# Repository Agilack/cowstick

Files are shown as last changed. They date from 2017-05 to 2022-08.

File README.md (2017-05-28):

# Cowstick

The goal of Cowstick project is to create usefull tools for microcontroller
and FPGA development, for example JTAG/SWD probes, serial port adapter ...
This tools are not revolutionnary in their functions but offer a more
user-friendly approach based on network communication.

## usbkey-ios

This is the first member of cowstick familly. At this time, this key is only
a proof of concept. It contains a microcontroller with USB interface, and
many configurable IOs.

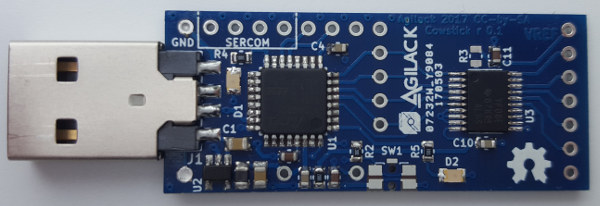
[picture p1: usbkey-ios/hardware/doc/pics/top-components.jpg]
Picture of cowstick usbkey


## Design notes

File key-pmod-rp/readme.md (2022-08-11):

PMOD usbkey
===========

This usb-key is part of cowstick boards family and offer a compact PMOD host
interface. It can be used to test or use most 3,3V PMOD devices, for other
power supplies, a level translator should be used.

For the moment, this module is not supported by cowlab but will be added
soon.

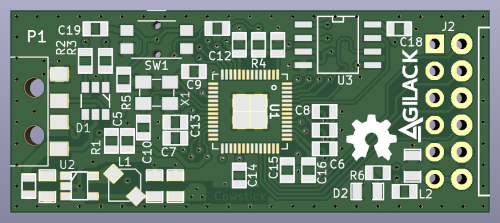
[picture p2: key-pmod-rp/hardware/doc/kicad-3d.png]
Preview of the board


CAD source
----------

This board has been designed using KiCad EDA (version 6). All sources files
(schematics, routing, ...) are available into the `hardware/prj-kicad` folder.

<table>
<tr>
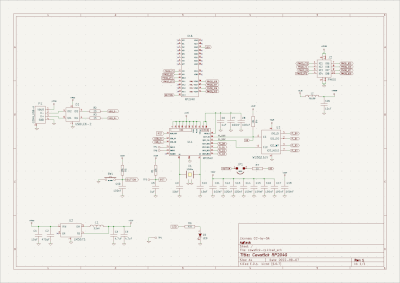
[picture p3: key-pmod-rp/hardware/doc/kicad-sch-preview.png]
KiCad schematics
<td></td>
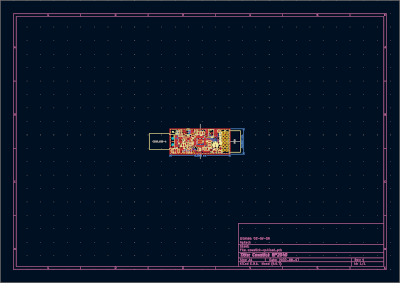
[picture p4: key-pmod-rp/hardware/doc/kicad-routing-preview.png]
KiCad routing
<td></td>
</tr>
<tr>
<td>Fig1: Preview of the KiCad schematics</td>
<td>Fig2: Preview of the KiCad routing</td>
</tr>
</table>

License
-------

This project is OpenHardware. You can use (and/or modify) this project under
terms of the Creative Commons ShareAlike license (CC-by-SA).
See [hardware/LICENSE.md](hardware/LICENSE.md).

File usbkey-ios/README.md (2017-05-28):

# Cowstick usbkey

This USB-key is part of the cowstick boards family. It is a very compact and
low-cost module that allow to connect and communicate with many serial ports
(like ICSP, JTAG, SPI, SWD, ...) over USB. This module can also be used with
cowlab tools to offer a user-friendly interface :)

Picture of cowstick usbkey

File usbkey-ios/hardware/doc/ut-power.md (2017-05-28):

Power unit-test
===============

The goal of this test is to validate the 3.3V regulator.

No load
-------

The first step is tu start the regulator without load. At this point a bug
has been detected : the EN pin mus NOT be left floating (see 7.4.3 of LM3671
datasheet). To fix this, a strap has been added between VIN and EN pin.

 * Input : 5V from laboratory power supply
 * Mesured output voltage (at TP3) : 3.38V
 * Mesured ripple : 29.2mV, main freq 30.30kHz

The device is in PFM mode, this values are acceptable.

Light load
----------

In this second test, a small resistive load (100ohm) has been connected to TP3.

 * Input : 5V (mesured input current : 30mA)
 * Mesured output voltage (at TP3) : 3.34V
 * Mesured ripple : 39.2mV

Large load
----------

This test has not been made yet.

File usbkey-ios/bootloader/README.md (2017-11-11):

# Cowstick Bootloader

To offer a simple and flexible firmware upgrade, cowstick contains a bootloader.
This program also provide an API to allow main application to reuse functions
and avoid multiple copies of generic methods. Here a list of main features :

  * Network oriented interface (show as Ethernet over USB interface),
  * Contains a minimalist HTTP server (not already available)
  * Small memory footprint (less than 20kB)
  * API to allow reuse functions into main firmware

# Usage

The bootloader is placed at the begining of flash memory, where processor
start code execution. In all cases, peripherals and low-level initialization
are made on startup (configure IOs, clocks, ...). At this point, three is
three possible behaviors :

 * If the push button is pressed on startup, cowstick start in bootloader
   mode.
 * Flash is read at address 0x4000. If a valid stack address is found
   (an address that point into internal SRAM) then, the bootloader get firmware
   entry address from second vector (at 0x4004) and jump at this address.
 * If no valid stack address is found, firmware is considered invalid and
   cowstick start in bootloader mode.

## License

CowStick-bootloader is free software: you can redistribute it and/or modify it
under the terms of the GNU Lesser General Public License version 3 as published
by the Free Software Foundation. You should have received a copy of the GNU
Lesser General Public License along with this program, see LICENSE.md file for
more details. This program is distributed WITHOUT ANY WARRANTY.

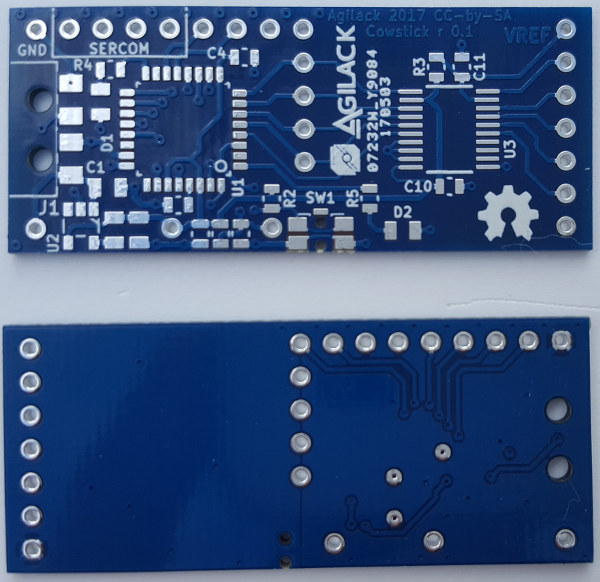
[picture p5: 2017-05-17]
usbkey-ios/hardware/doc/pics/pcb-only.jpg

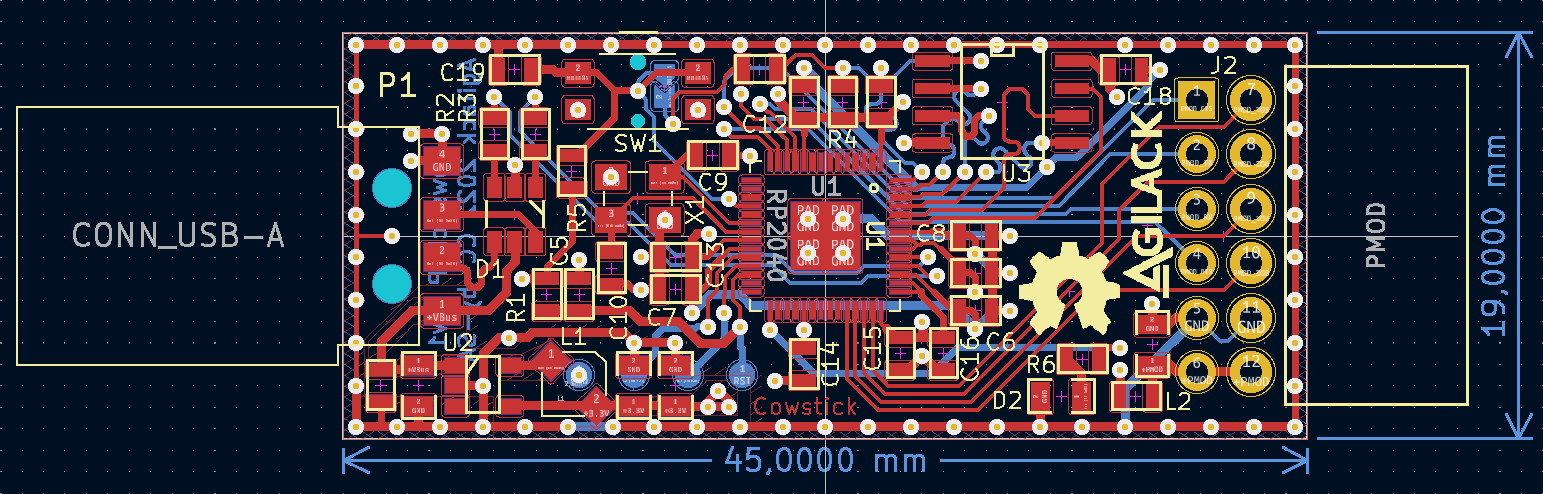
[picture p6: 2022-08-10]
key-pmod-rp/hardware/doc/pcb-preview.png

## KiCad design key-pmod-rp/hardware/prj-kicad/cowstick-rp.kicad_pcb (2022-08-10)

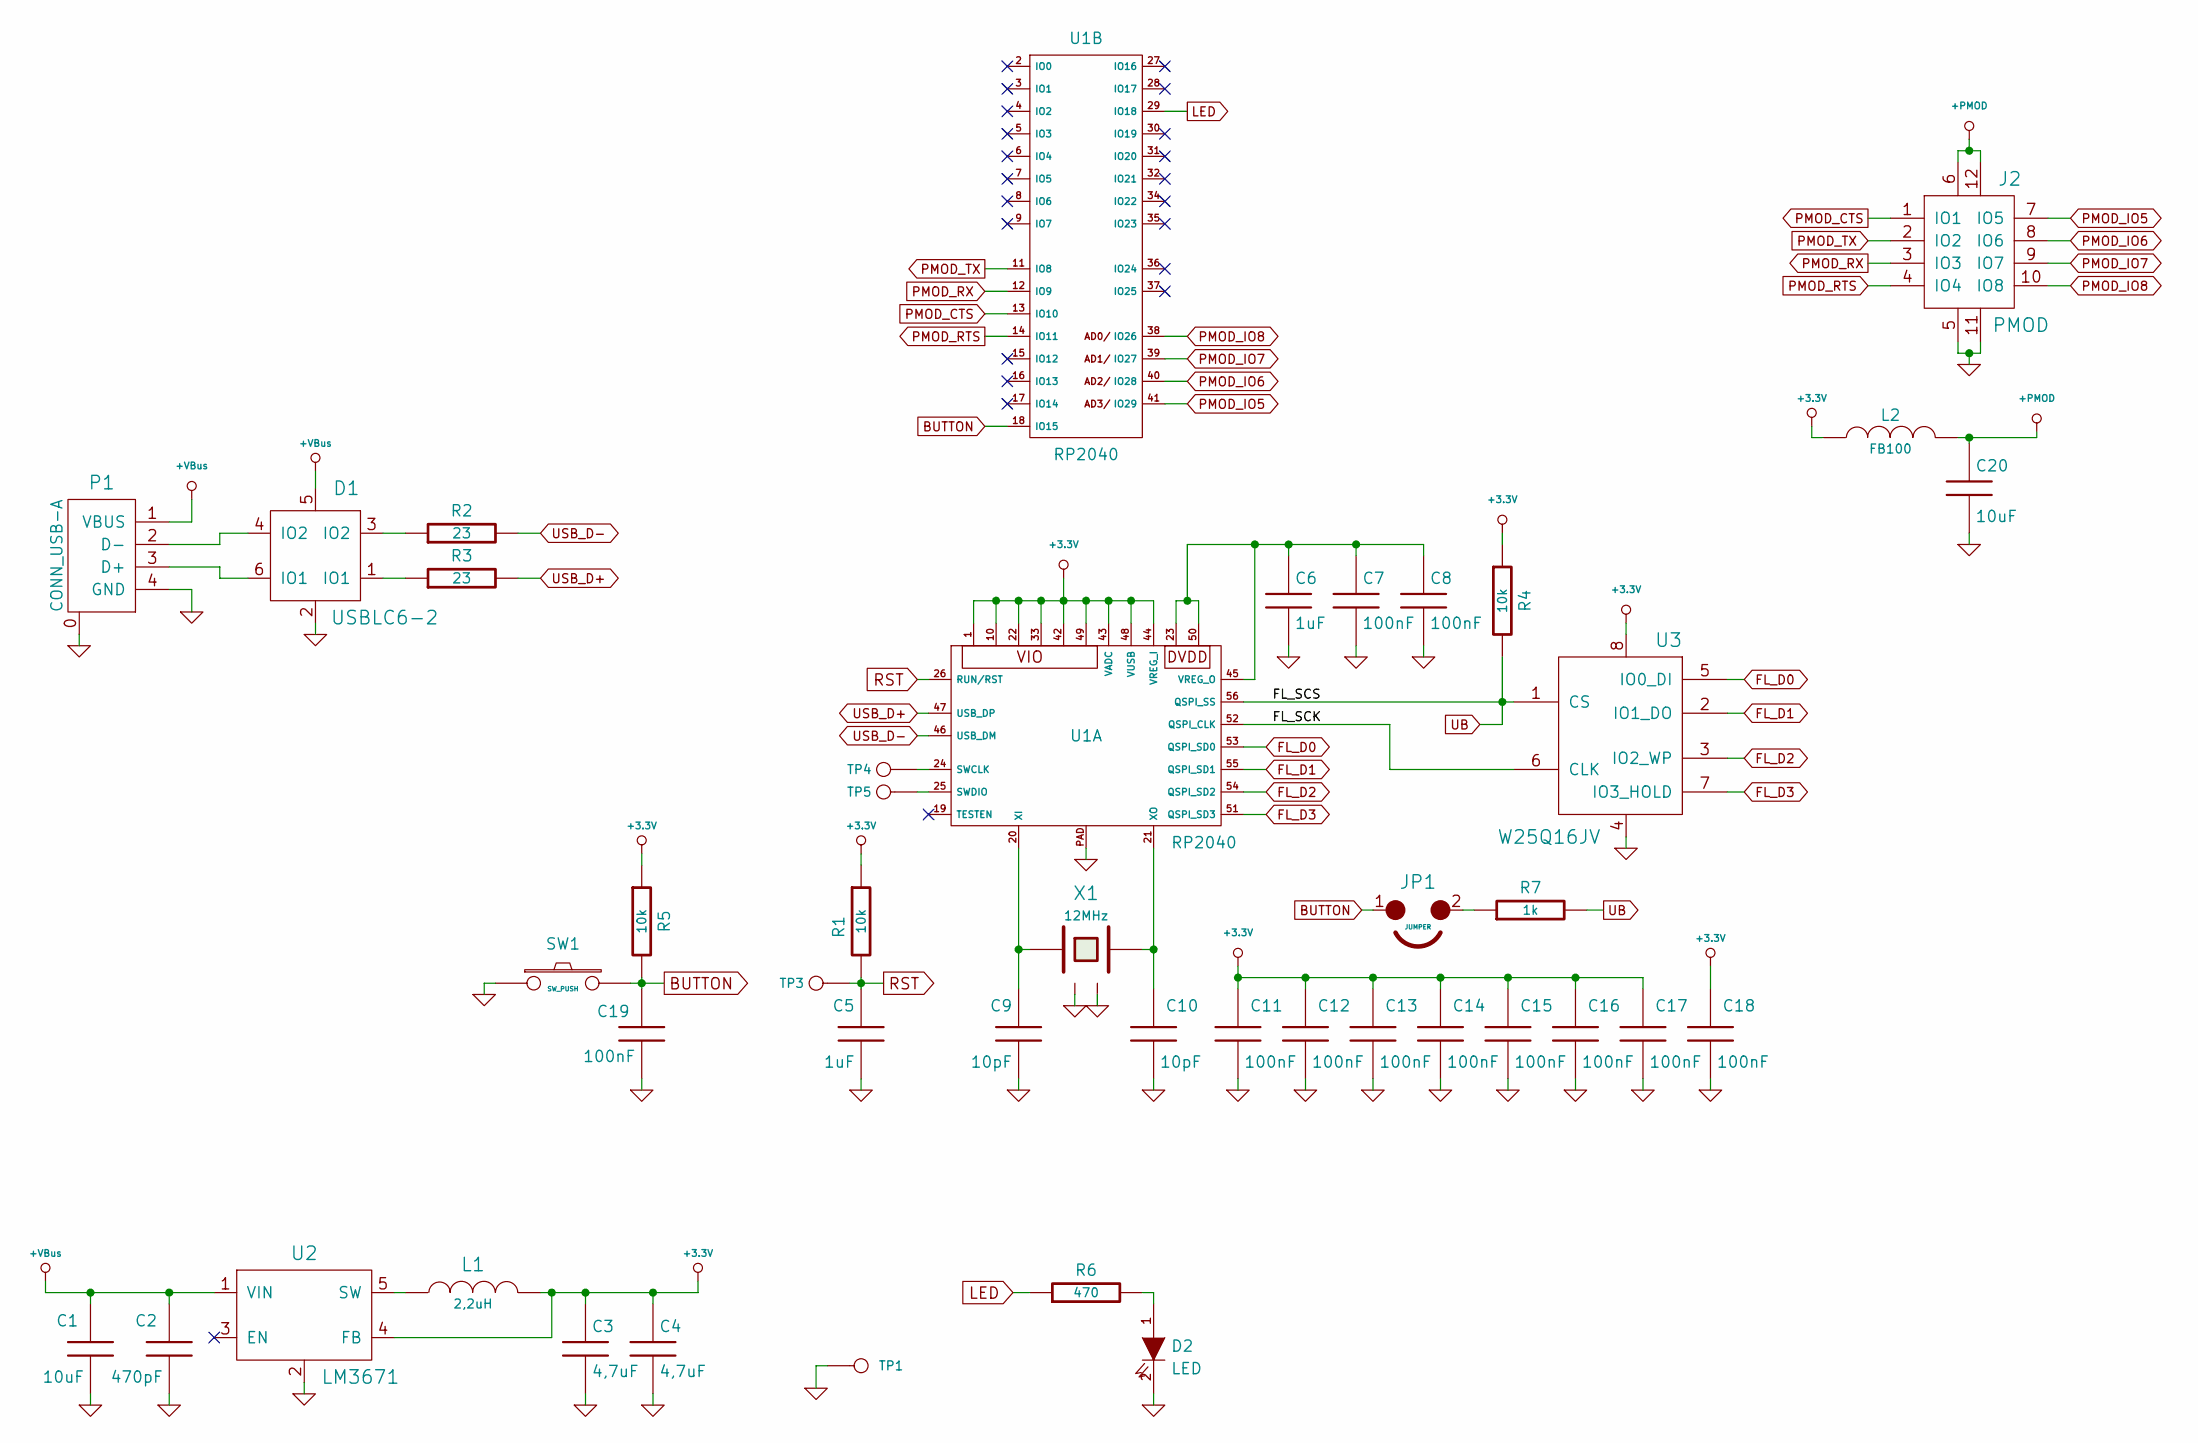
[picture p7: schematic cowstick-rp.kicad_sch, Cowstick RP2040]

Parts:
C1, C20: 10uF; SMD0805
C2: 470pF; SMD0603
C3, C4: 4,7uF; SMD0805
C5, C6: 1uF; SMD0603
C7, C8, C11, C12, C13, C14, C15, C16, C17, C18, C19: 100nF; SMD0603
C9, C10: 10pF; SMD0603
D1: USBLC6-2; SOT23-6
D2: LED; SMD0805
J2: PMOD; PMOD_SSW106-RA
JP1: JUMPER; TP_JP
L1: 2,2uH; I_CDRH2D14
L2: FB100; SMD0603
P1: CONN_USB-A; CONN_MC32604
R1, R4, R5: 10k; SMD0603
R2, R3: 23; SMD0603
R6: 470; SMD0603
R7: 1k; SMD0603
SW1: SW_PUSH; SW_436351045816
TP1, TP3, TP4, TP5: CONN_1; TP_SMD
U1: RP2040; QFN56
U2: LM3671; SOT23-5
U3: W25Q16JV; SOIC-8
X1: 12MHz; Q_3.2x2.5

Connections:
+3.3V: C3.1, C4.1, C11.1, C12.1, C13.1, C14.1, C15.1, C16.1, C17.1, C18.1, L1.2, L2.1, R1.1, R4.1, R5.1, U1.1, U1.10, U1.22, U1.33, U1.42, U1.43 (VADC), U1.44 (VREG_I), U1.48 (VUSB), U1.49, U2.4 (FB), U3.8
+PMOD: C20.1, J2.6, J2.12, L2.2
+VBus: C1.1, C2.1, D1.5, P1.1 (VBUS), U2.1 (VIN)
/FL_SCK: U1.52 (QSPI_CLK), U3.6 (CLK)
BUTTON: C19.1, JP1.1, R5.2, SW1.2, U1.18 (IO15)
FL_D0: U1.53 (QSPI_SD0), U3.5 (IO0_DI)
FL_D1: U1.55 (QSPI_SD1), U3.2 (IO1_DO)
FL_D2: U1.54 (QSPI_SD2), U3.3 (IO2_WP)
FL_D3: U1.51 (QSPI_SD3), U3.7 (IO3_HOLD)
GND: C1.2, C2.2, C3.2, C4.2, C5.2, C6.2, C7.2, C8.2, C9.2, C10.2, C11.2, C12.2, C13.2, C14.2, C15.2, C16.2, C17.2, C18.2, C19.2, C20.2, D1.2, D2.2 (K), J2.5, J2.11, P1.0, P1.4 (GND), SW1.1, TP1.1, U1.PAD, U2.2, U3.4, X1.2, X1.4
LED: R6.1, U1.29 (IO18)
unnamed: C6.1, C7.1, C8.1, U1.23, U1.45 (VREG_O), U1.50
unnamed: C9.1, U1.20 (XI), X1.1
unnamed: C10.1, U1.21 (XO), X1.3
unnamed: D1.1 (IO1), R3.1
unnamed: D1.3 (IO2), R2.1
unnamed: D1.4 (IO2), P1.2 (D-)
unnamed: D1.6 (IO1), P1.3 (D+)
unnamed: D2.1 (A), R6.2
unnamed: L1.1, U2.5 (SW)
unnamed: JP1.2, R7.1
unnamed: TP4.1, U1.24 (SWCLK)
unnamed: TP5.1, U1.25 (SWDIO)
PMOD_CTS: J2.1 (IO1), U1.13 (IO10)
PMOD_IO5: J2.7 (IO5), U1.41 (IO29)
PMOD_IO6: J2.8 (IO6), U1.40 (IO28)
PMOD_IO7: J2.9 (IO7), U1.39 (IO27)
PMOD_IO8: J2.10 (IO8), U1.38 (IO26)
PMOD_RTS: J2.4 (IO4), U1.14 (IO11)
PMOD_RX: J2.3 (IO3), U1.12 (IO9)
PMOD_TX: J2.2 (IO2), U1.11 (IO8)
RST: C5.1, R1.2, TP3.1, U1.26 (RUN/RST)
UB: R4.2, R7.2, U1.56 (QSPI_SS), U3.1 (CS)
USB_D+: R3.2, U1.47 (USB_DP)
USB_D-: R2.2, U1.46 (USB_DM)

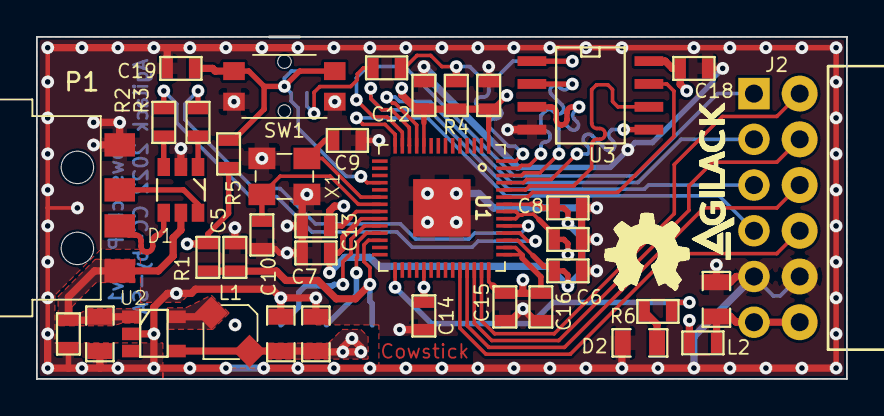
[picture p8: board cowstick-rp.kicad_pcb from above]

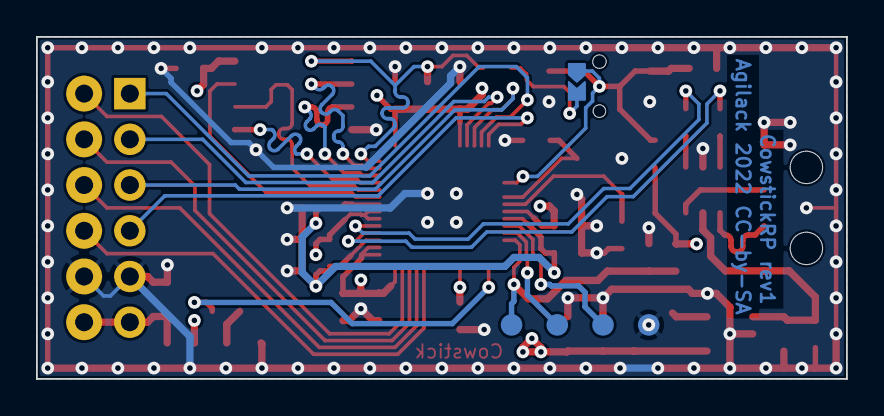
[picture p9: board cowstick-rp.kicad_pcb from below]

Board: 4 copper layers, 45.0 x 19.0 mm, 45 parts (5 on the bottom side), 35 nets.

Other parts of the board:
agilack-11.5: 450px; logo-agilack
ohw_logo: VAL**; logo-ohw

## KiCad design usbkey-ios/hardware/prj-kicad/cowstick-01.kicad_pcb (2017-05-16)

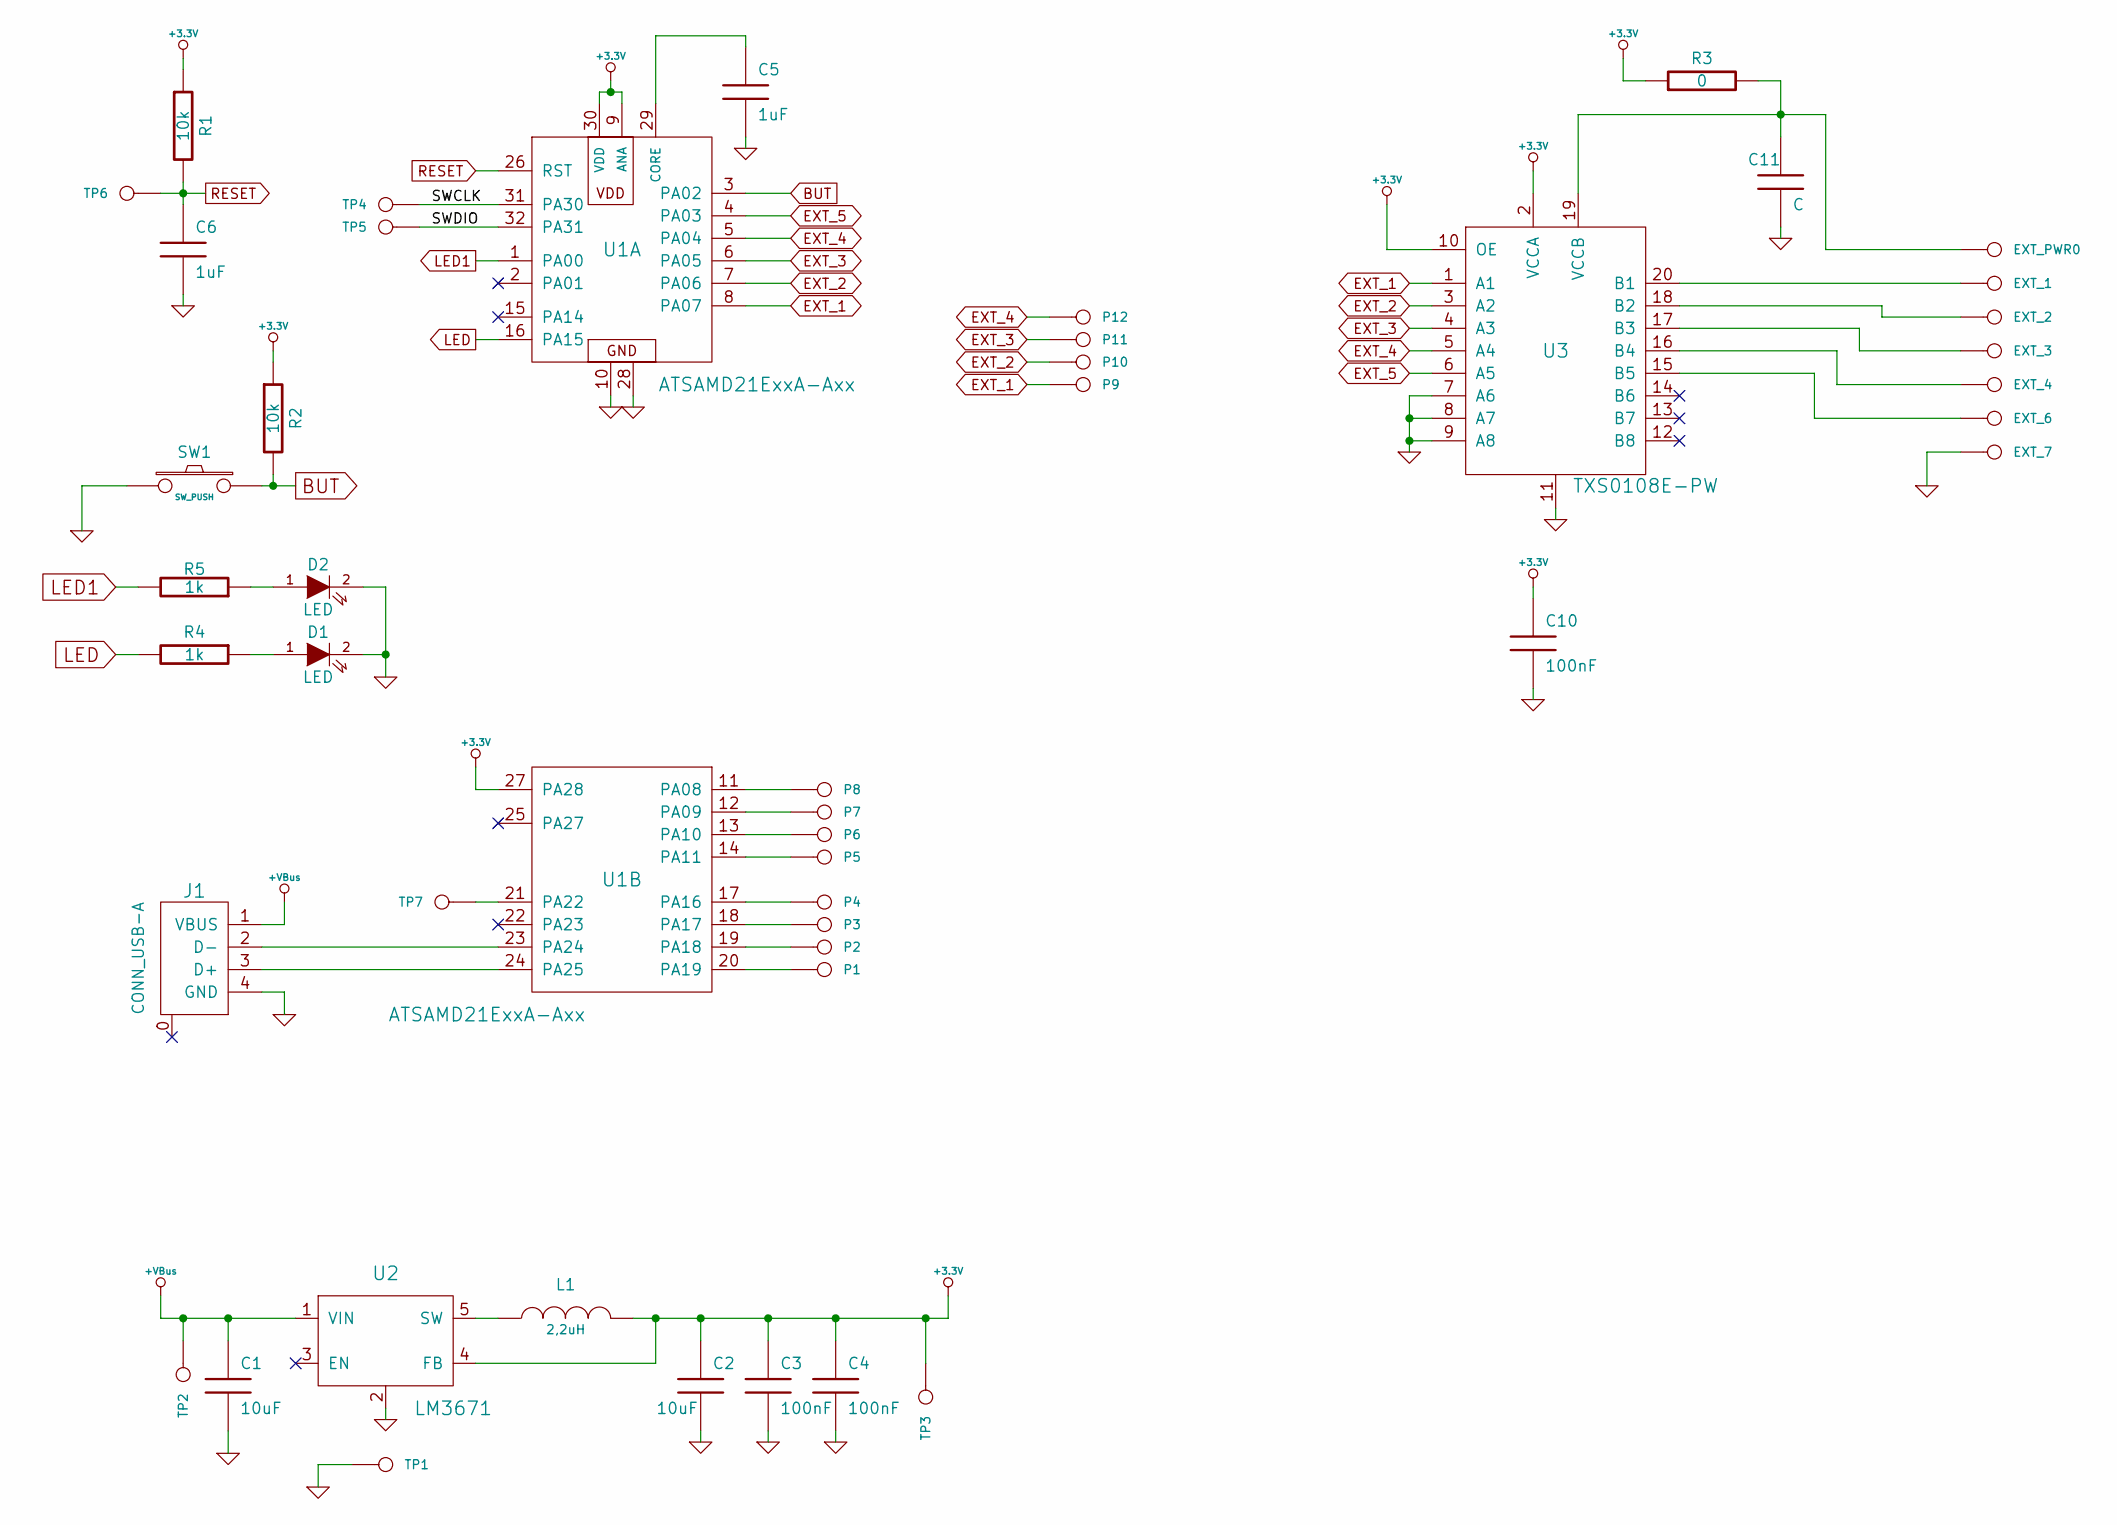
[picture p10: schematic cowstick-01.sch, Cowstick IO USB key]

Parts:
C1, C2: 10uF; SMD0805
C3, C4, C10: 100nF; SMD0603
C5, C6: 1uF; SMD0603
C11: C; SMD0603
D1, D2: LED; SMD0805
EXT_1, EXT_2, EXT_3, EXT_4, EXT_6, EXT_7: CONN_1; TP
EXT_PWR0: CONN_1; TP
J1: CONN_USB-A; CONN_MC32604
L1: 2,2uH; SMD0805
P1, P2, P3, P4, P5, P6, P7, P8, P9, P10, P11, P12: CONN_1; TP
R1, R2: 10k; SMD0603
R3: 0; SMD0603
R4, R5: 1k; SMD0603
SW1: SW_PUSH; SW_PTS840
TP1, TP2, TP3, TP6: CONN_1; TP
TP4, TP5, TP7: CONN_1; TP_SMD
U1: ATSAMD21ExxA-Axx; TQFP32
U2: LM3671; SOT23-5
U3: TXS0108E-PW; TSSOP20

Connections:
+3.3V: C2.1, C3.1, C4.1, C10.1, L1.2, R1.1, R2.1, R3.1, TP3.1, U1.9 (ANA), U1.27 (PA28), U1.30 (VDD), U2.4 (FB), U3.2 (VCCA), U3.10 (OE)
+VBus: C1.1, J1.1 (VBUS), TP2.1, U2.1 (VIN)
/SWCLK: TP4.1, U1.31 (PA30)
/SWDIO: TP5.1, U1.32 (PA31)
BUT: R2.2, SW1.1, U1.3 (PA02)
EXT_1: P9.1, U1.8 (PA07), U3.1 (A1)
EXT_2: P10.1, U1.7 (PA06), U3.3 (A2)
EXT_3: P11.1, U1.6 (PA05), U3.4 (A3)
EXT_4: P12.1, U1.5 (PA04), U3.5 (A4)
EXT_5: U1.4 (PA03), U3.6 (A5)
GND: C1.2, C2.2, C3.2, C4.2, C5.2, C6.2, C10.2, C11.2, D1.2 (K), D2.2 (K), EXT_7.1, J1.4 (GND), SW1.2, TP1.1, U1.10, U1.28, U2.2, U3.7 (A6), U3.8 (A7), U3.9 (A8), U3.11
LED: R4.2, U1.16 (PA15)
LED1: R5.2, U1.1 (PA00)
unnamed: C5.1, U1.29 (CORE)
unnamed: C11.1, EXT_PWR0.1, R3.2, U3.19 (VCCB)
unnamed: D1.1 (A), R4.1
unnamed: D2.1 (A), R5.1
unnamed: EXT_1.1, U3.20 (B1)
unnamed: EXT_2.1, U3.18 (B2)
unnamed: EXT_3.1, U3.17 (B3)
unnamed: EXT_4.1, U3.16 (B4)
unnamed: EXT_6.1, U3.15 (B5)
unnamed: J1.2 (D-), U1.23 (PA24)
unnamed: J1.3 (D+), U1.24 (PA25)
unnamed: L1.1, U2.5 (SW)
unnamed: P1.1, U1.20 (PA19)
unnamed: P2.1, U1.19 (PA18)
unnamed: P3.1, U1.18 (PA17)
unnamed: P4.1, U1.17 (PA16)
unnamed: P5.1, U1.14 (PA11)
unnamed: P6.1, U1.13 (PA10)
unnamed: P7.1, U1.12 (PA09)
unnamed: P8.1, U1.11 (PA08)
unnamed: TP7.1, U1.21 (PA22)
RESET: C6.1, R1.2, TP6.1, U1.26 (RST)

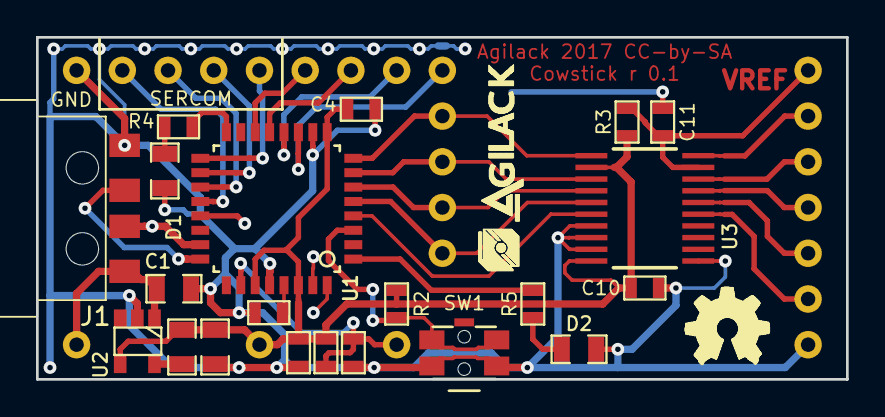
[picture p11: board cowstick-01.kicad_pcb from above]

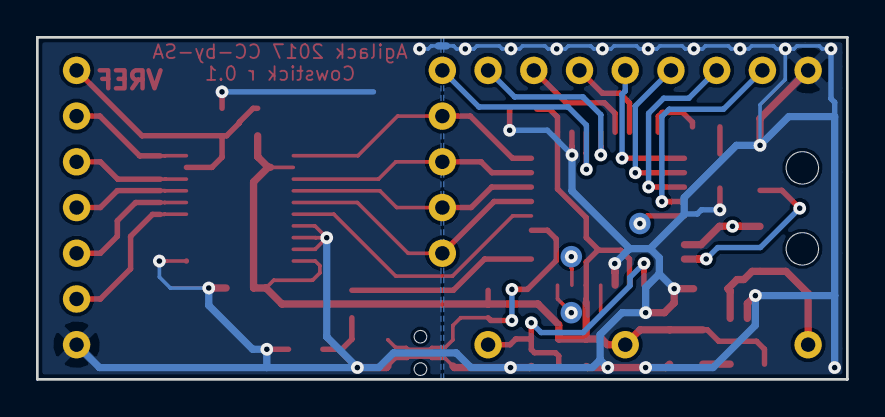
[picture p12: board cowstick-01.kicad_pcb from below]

Board: 2 copper layers, 45.0 x 19.0 mm, 49 parts (3 on the bottom side), 35 nets.

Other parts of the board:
agilack-11.5: 450px; agilack-11.5
ohw_logo: VAL**; ohw-logo

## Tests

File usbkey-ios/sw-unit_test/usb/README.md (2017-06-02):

# USB unit-test

The goal of this program is to develop a USB stack for cowstick. This is put
into a unit-test to offer a simple way to test it :)

## Why ??

If your read this the first question that comes to mind is probably "Why a
custom USB stack ?" There are two main reasons :

 * The "official" atmel/microchip stack use static datas (like usb_d_inst or
   dev_inst) For cowstick, i want to share code of USB stack between bootloader
   and firmware and that's a bit more difficult with static datas.

 * All the stacks i've seen are written to be portable and/or generic. This
   is great but use lot of code. This one is made to have a small memory
   footprint. I want (i hope) a bootloader that fits into less than 16kB.

## HID Mouse

The unit-test contains an HID mouse. This is one of the simplest device (only
one endpoint) that is easy to test (detected by all OS). When loaded this
virtual mouse will move automatically into a square.

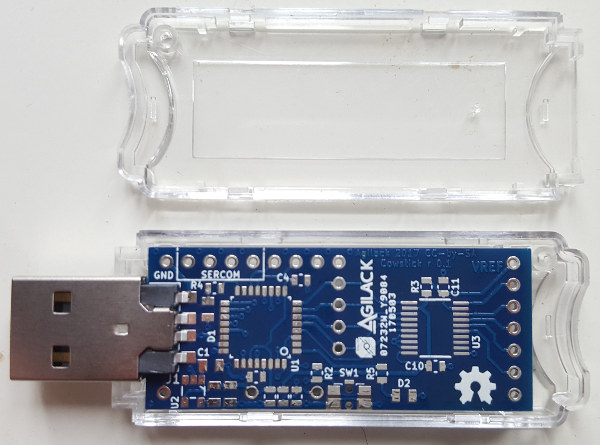
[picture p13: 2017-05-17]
usbkey-ios/hardware/doc/pics/enclosure-test.jpg

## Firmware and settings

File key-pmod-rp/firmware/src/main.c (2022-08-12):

/**
 * @file  main.c
 * @brief Entry point and main function of the firmware
 *
 * @author Saint-Genest Gwenael <gwen@cowlab.fr>
 * @copyright Cowlab (c) 2022
 *
 * @page License
 * This firmware is free software: you can redistribute it and/or modify it
 * under the terms of the GNU General Public License version 3 as published
 * by the Free Software Foundation. You should have received a copy of the
 * GNU General Public License along with this program, see LICENSE.md file
 * for more details.
 * This program is distributed WITHOUT ANY WARRANTY.
 */
#include "pico/stdlib.h"
#include <stdlib.h>
#include <stdio.h>
#include <string.h>
#include <ctype.h>
#include "serial.h"

#undef USE_ECHO

void u_process(void);

/**
 * @brief Entry point of C code
 *
 * This function is called by low-level reset handler. This can be after a
 * power-on, an hardware or software reboot, and after some critical errors.
 * This function should never returns.
 */
int main()
{
	stdio_init_all();

	/* Wait a bit after start to allow VCP to resync */
	sleep_ms(2000);
	printf("--=={ Cowstick-RP }==--\n");

	serial_init();

	while(1)
	{
		if (serial_rx_avail() > 0)
			u_process();
	}
}

void u_process(void)
{
	char data[64];
	char msg[80];
	int len;

	memset(data, 0, 64);
	/* Get data received from uart */
	serial_read(data, 63);
	/* Write debug message to standard output */
	sprintf(msg, "[%s]\r\n", data);
	printf("%s", data);
#ifdef USE_ECHO
	/* Send debug message to uart itself as echo */
	serial_write(msg, strlen(msg));
#endif
}
/* EOF */

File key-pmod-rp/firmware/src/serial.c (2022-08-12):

/**
 * @file  serial.c
 * @brief Handle communication with UART interface
 *
 * @author Saint-Genest Gwenael <gwen@cowlab.fr>
 * @copyright Cowlab (c) 2022
 *
 * @page License
 * This firmware is free software: you can redistribute it and/or modify it
 * under the terms of the GNU General Public License version 3 as published
 * by the Free Software Foundation. You should have received a copy of the
 * GNU General Public License along with this program, see LICENSE.md file
 * for more details.
 * This program is distributed WITHOUT ANY WARRANTY.
 */
#include "pico/stdlib.h"
#include "hardware/irq.h"
#include "hardware/uart.h"
#include "serial.h"

static void serial_irq(void);

static uint8_t rx_buffer[SERIAL_RX_SZ];
static volatile int rx_index_r, rx_index_w;

/**
 * @brief Initialize the "serial" module
 *
 * This function initialize the serial module and configure UART interface. For
 * this driver to work properly, this function must be called before any other
 * serial functions.
 */
void serial_init(void)
{
	/* Initialize indexes of buffers */
	rx_index_r = 0;
	rx_index_w = 0;

	uart_init(uart1, 115200);

	gpio_set_function(8, GPIO_FUNC_UART);
	gpio_set_function(9, GPIO_FUNC_UART);

	/* Set default/initial UART configuration */
	uart_set_hw_flow(uart1, false, false);
	uart_set_format (uart1, 8, 1, UART_PARITY_NONE);
	uart_set_fifo_enabled(uart1, false);

	/* Configure interrupts */
	irq_set_exclusive_handler(UART1_IRQ, serial_irq);
	irq_set_enabled(UART1_IRQ, true);
	uart_set_irq_enables(uart1, true, false);
}

/**
 * @brief Read bytes from rx buffer
 *
 * Bytes received from UART are handled by interrupt (see serial_irq) and put
 * into a buffer. This function allow to extract bytes from this rx buffer.
 *
 * @param buffer Pointer to a buffer where to put data
 * @param len    Maximum number of bytes to read
 * @return integer Number of readed bytes
 */
int serial_read(char *buffer, int len)
{
	int count = 0;

	/* Sanity check */
	if (buffer == 0)
		return(0);

	while (count < len)
	{
		/* If the rx buffer is empty, nothing more to do */
		if (rx_index_r == rx_index_w)
			break;

		/* Read one byte from rx buffer */
		*buffer++ = rx_buffer[rx_index_r];
		count++;
		/* Update index */
		rx_index_r++;
		if (rx_index_r == SERIAL_RX_SZ)
			rx_index_r = 0;
	}
	return(count);
}

/**
 * @brief Get the number of bytes available into receive buffer
 *
 * @return integer Number of received bytes
 */
int serial_rx_avail(void)
{
	int r_copy, w_copy;
	int len;

	if (rx_index_r == rx_index_w)
		return(0);

	/* Save a copy of indexes */
	r_copy = rx_index_r;
	w_copy = rx_index_w;

	if (w_copy > r_copy)
		len = (w_copy - r_copy);
	else
		len = (SERIAL_RX_SZ - r_copy) + w_copy;

	return(len);
}

/**
 * @brief Send bytes to UART
 *
 * @param data Pointer to a buffer with data to send
 * @param len  Number of bytes to send
 */
void serial_write(uint8_t *data, int len)
{
	int i;

	/* Sanity check */
	if (data == 0)
		return;

	for (i = 0; i < len; i++)
		uart_putc_raw(uart1, data[i]);
}

/**
 * @brief UART interrupt handler
 *
 * This function is called when an interrupt is raised by the UART peripheral
 * (mainly on received byte event)
 */
static void serial_irq(void)
{
	uart_hw_t *dev;
	uint32_t ris;
	uint8_t c;
	int idx_next;

	dev = uart_get_hw(uart1);

	/* Get the Raw Interrupt Status */
	ris = dev->ris;

	/* Receive Timeout is not really used, disable it */
	if (ris & (1 << 6))
		dev->imsc &= ~(1 << 6);

	/* If one byte has been received */
	if (ris & UART_UARTRIS_RXRIS_BITS)
	{
		c = (dev->dr & 0xFF);
		rx_buffer[rx_index_w] = c;

		/* Compute index of next byte into circular buffer */
		idx_next = rx_index_w + 1;
		if (idx_next == SERIAL_RX_SZ)
			idx_next = 0;
		/* If buffer is not full, update write index */
		if (idx_next != rx_index_r)
			rx_index_w = idx_next;
	}
}
/* EOF */

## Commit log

2017-05-09 = Create a new cowstick board : USBKEY-IOs - Add schematic and component library
    [cowstick-01.sch]
2017-05-10 = Create footprint library and netlist
    [cowstick-01.kicad_pcb]
2017-05-11 = Add PCB routing (full version, not verified)
    [cowstick-01.kicad_pcb]
2017-05-11 = Add production files (gerber + drill)
    [cowstick-01-B.Cu.gbr, cowstick-01-B.Mask.gbr, cowstick-01-B.Paste.gbr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]
2017-05-12 = ADD a unit-test for the status LED
    [doxygen.cfg]
2017-05-16 =UPD: update title, date and license into schematics and routing documents
    [cowstick-01.kicad_pcb, cowstick-01.sch]
2017-05-16 = ADD a unit-test for the UART
    [doxygen.cfg]
2017-05-17 = ADD: First pictures of the PCB :)
2017-05-18 = ADD: Picture of the PCB with components
2017-05-19 = ADD: Unit -tes for 3V3 power supply
2017-05-22 = ADD: Unit-test for status LED ... using TCC peripheral
    [doxygen.cfg]
2017-05-23 = ADD: Unit-test skeleton for USB device (now, only PLL config for 48MHz clock)
2017-05-24 = UPD: USB unit-test, config peripheral and attach to bus
2017-05-24 = UPD: USB unit-test, improve endpoint initial config, interrupt skeleton
2017-05-26 = UPD: USB unit-test, improve interrupt handling, move GET_DESCRIPTOR case to a dedicated function
2017-05-27 = DOC: USB unit-test, add comments and doxygen config to generate doc
    [doxygen.cfg]
2017-05-29 = UPD: USB unit-test, Create a structure of device callbacks, add HID Report descriptor
2017-05-29 = UPD: USB unit-test, modify endpoint enable sequence, fix address of endpoint registers (other than EP0)
    [main.c]
2017-05-30 = UPD: USB unit-test, fix bug into DFLL init : use NVM calibration config for coarse parameter
    [hardware.c]
2017-06-05 UPD: import led status functions into bootloader (from unit-test)
2017-06-06 Update bootloader: jump on main firmware or start bootloader according to button state at power-on
2017-06-07 Bootloader: import uart functions (for auxilary debug port)
2017-11-02 Bootloader: add ARP support to network layer (only answer to req for board ip)
2017-11-10 Bootloader: Small fix (number of interfaces into USB descriptors) and cleanups
    [net_ipv4.c]
2017-11-23 Bootloader: fix some issues into tcp trasmit and close
    [main.c, net_ipv4.c]
2017-12-08 Bootloader: add service to upgrade memory with a raw buffer sent over a TCP socket (direct-socket-upgrade)
2022-08-07 KeyPMOD: --=={ Create a new board "key-pmod-rp" }==--
    [cowstick-rp.kicad_pcb, cowstick-rp.kicad_sch]
2022-08-08 KeyPMOD: Improve PCB r1, add power supply (5V->3V3)
    [cowstick-rp.kicad_pcb, cowstick-rp.kicad_sch]
2022-08-09 KeyPMOD: Improve PCB r1, add RP2040 mcu (include crystal and decoupling caps)
    [cowstick-rp.kicad_pcb, cowstick-rp.kicad_sch]
2022-08-10 KeyPMOD: Add flash memory and USB protection. Design of board rev1 mostly finish
    [cowstick-rp.kicad_pcb, cowstick-rp.kicad_sch]
2022-08-11 KeyPMOD: Create production files for pcb rev1
    [cowstick-rp-B_Cu.gbr, cowstick-rp-B_Mask.gbr, cowstick-rp-B_Paste.gbr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]
2022-08-12 KeyPMOD: Create firmware skeleton, add basic driver for UART

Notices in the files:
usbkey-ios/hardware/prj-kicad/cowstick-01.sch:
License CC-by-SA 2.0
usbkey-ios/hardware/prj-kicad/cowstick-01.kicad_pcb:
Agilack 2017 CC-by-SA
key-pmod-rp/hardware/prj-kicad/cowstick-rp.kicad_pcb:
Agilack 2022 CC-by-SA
